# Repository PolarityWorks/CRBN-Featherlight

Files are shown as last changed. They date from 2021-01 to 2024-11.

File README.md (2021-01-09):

# CRBN-Featherlight

<br />The CRBN Featherlight is licensed under a <a rel="license" href="http://creativecommons.org/licenses/by-nc-sa/4.0/">Creative Commons Attribution-NonCommercial-ShareAlike 4.0 International License</a>.

The PCB and case design may be freely reproduced, modified, and manufactured for personal use and may not be reproduced for public sale.

If you have built upon this work please contact us at polarity.works.1@gmail.com. We fully support those looking to make new things and will most likely support your project.

[Build Guide](https://drive.google.com/file/d/1sr51WLZUvYGmcUbsTRLLeZIsZQXj4blm/view)

[Kits are sold here](https://keygem.store/collections/keyboards/products/group-buy-featherlight-40-kit)

[QMK Firmware](https://config.qmk.fm/#/crbn/LAYOUT_crbn_1x2u)

[ZMK Firmware](https://github.com/zmkfirmware/zmk/tree/main)

This little 40% ortho punches well above its weight and its price tag. Tough enough to survive life on the go or beating down someone that disses it.
It's got all the configuration options you'd ever want in a 40%. All the components are through-hole so it's a great first keyboard kit to put togethether.
You will need a pro micro for the PCB which gives you lots of options for extra features. You can solder in an elite c to get USB C or even a nice nano to make it wireless! There's plenty of room between the PCB and the bottom plate for a huge lithium battery.
This would be a vicious travel keyboard, a macro pad for productivity people, the first ortho for people who want to try ortho, or just a cute little keyboard to lend to people when they need one.

## Specifications
* Only 300g
* Stacked carbon fiber switch plate and bottom
* Supoport for a rotary encoder - this can be place in one of the corners
* Sevral bottom row layouts
* QMK and ZMK support

Main

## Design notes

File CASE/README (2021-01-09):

Dimensions:
Switch Plate thickness - 1.5mm
Bottom Plate thickness - 2mm
Inside corner radius - 1mm

Hardware needed:
M2x4mm machine screws   x24
M2x3mm M-F standoffs    x12
M2x6mm F-F standoffs    x12
M2x0.5mm washers        x12

M2x6mm machine screws   x2   (If using the optional feet)

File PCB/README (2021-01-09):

Components Needed:
1N4148 DO-35 Diodes               x48
6x6mm tactile button              x1
12x1 pin header 2.54mm pitch      x2
Pro Micro Compatible or Nice Nano x1
Key Switches                      x44-48

Optional:
EC11 Rotary Encoder               x1
Stabilisers (2u or 4u)            x1-2

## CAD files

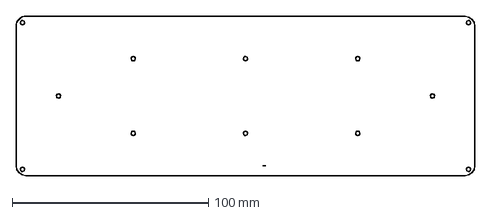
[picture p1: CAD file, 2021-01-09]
CASE/Bottom Plate.dxf
233.6 x 81.2 mm

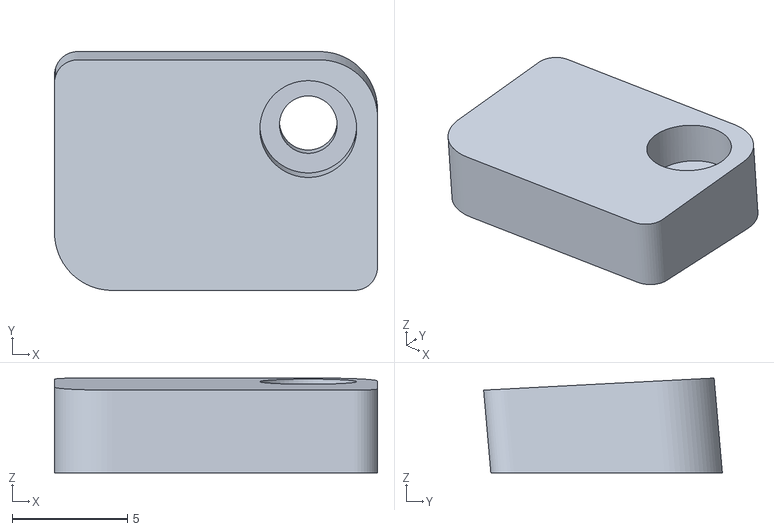
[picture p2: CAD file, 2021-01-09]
CASE/FEET/Foot - 3 degrees.stl
14.0 x 10.4 x 4.11

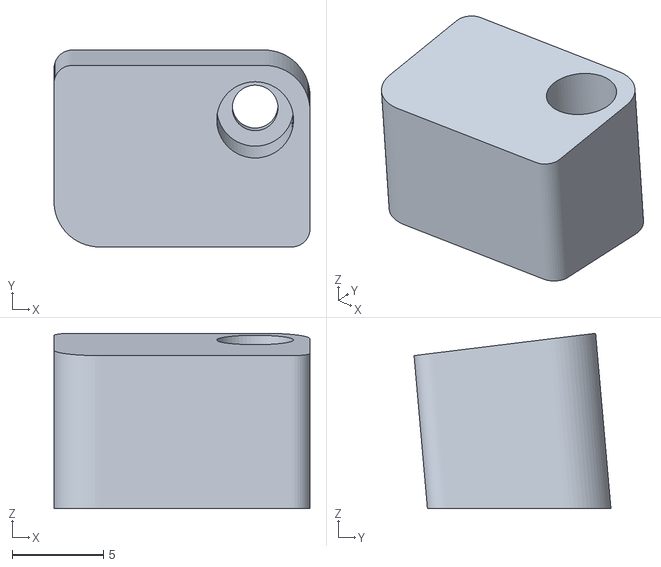
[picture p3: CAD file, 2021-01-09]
CASE/FEET/Foot - 7 degrees.stl
14.0 x 10.8 x 9.59

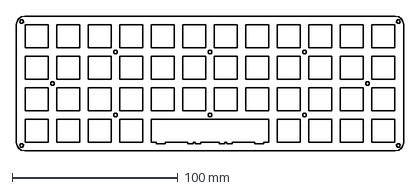
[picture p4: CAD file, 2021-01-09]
CASE/Switch Plate.dxf
233.6 x 81.2 mm

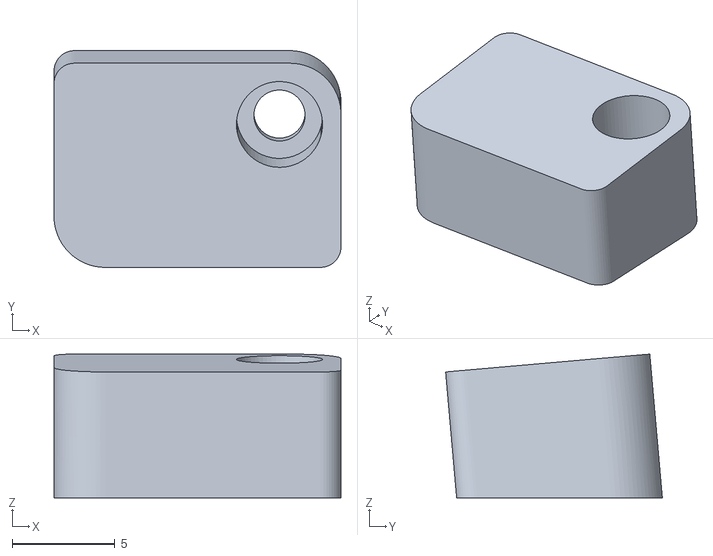
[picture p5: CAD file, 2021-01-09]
CASE/FEET/Foot - 5 degrees.stl
14.0 x 10.6 x 7.02

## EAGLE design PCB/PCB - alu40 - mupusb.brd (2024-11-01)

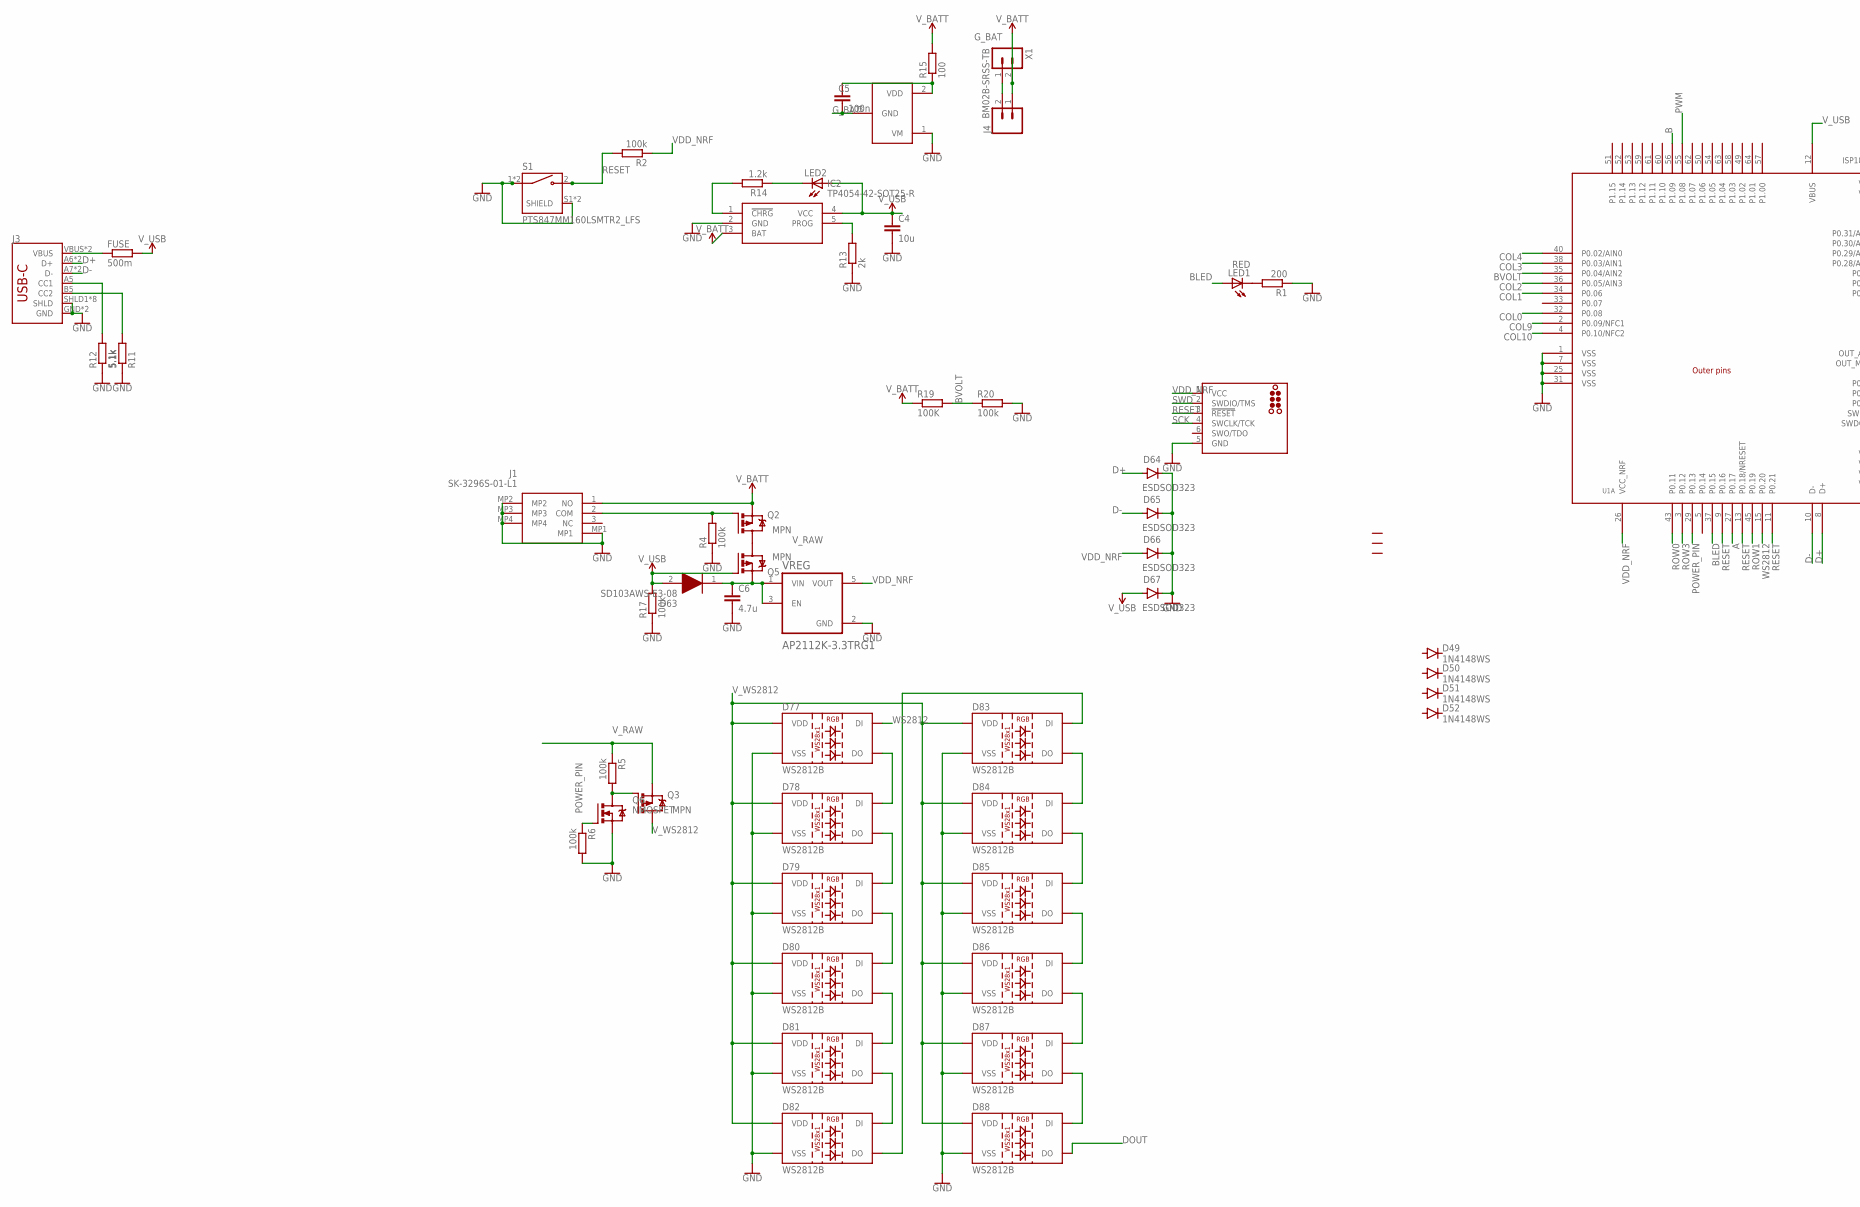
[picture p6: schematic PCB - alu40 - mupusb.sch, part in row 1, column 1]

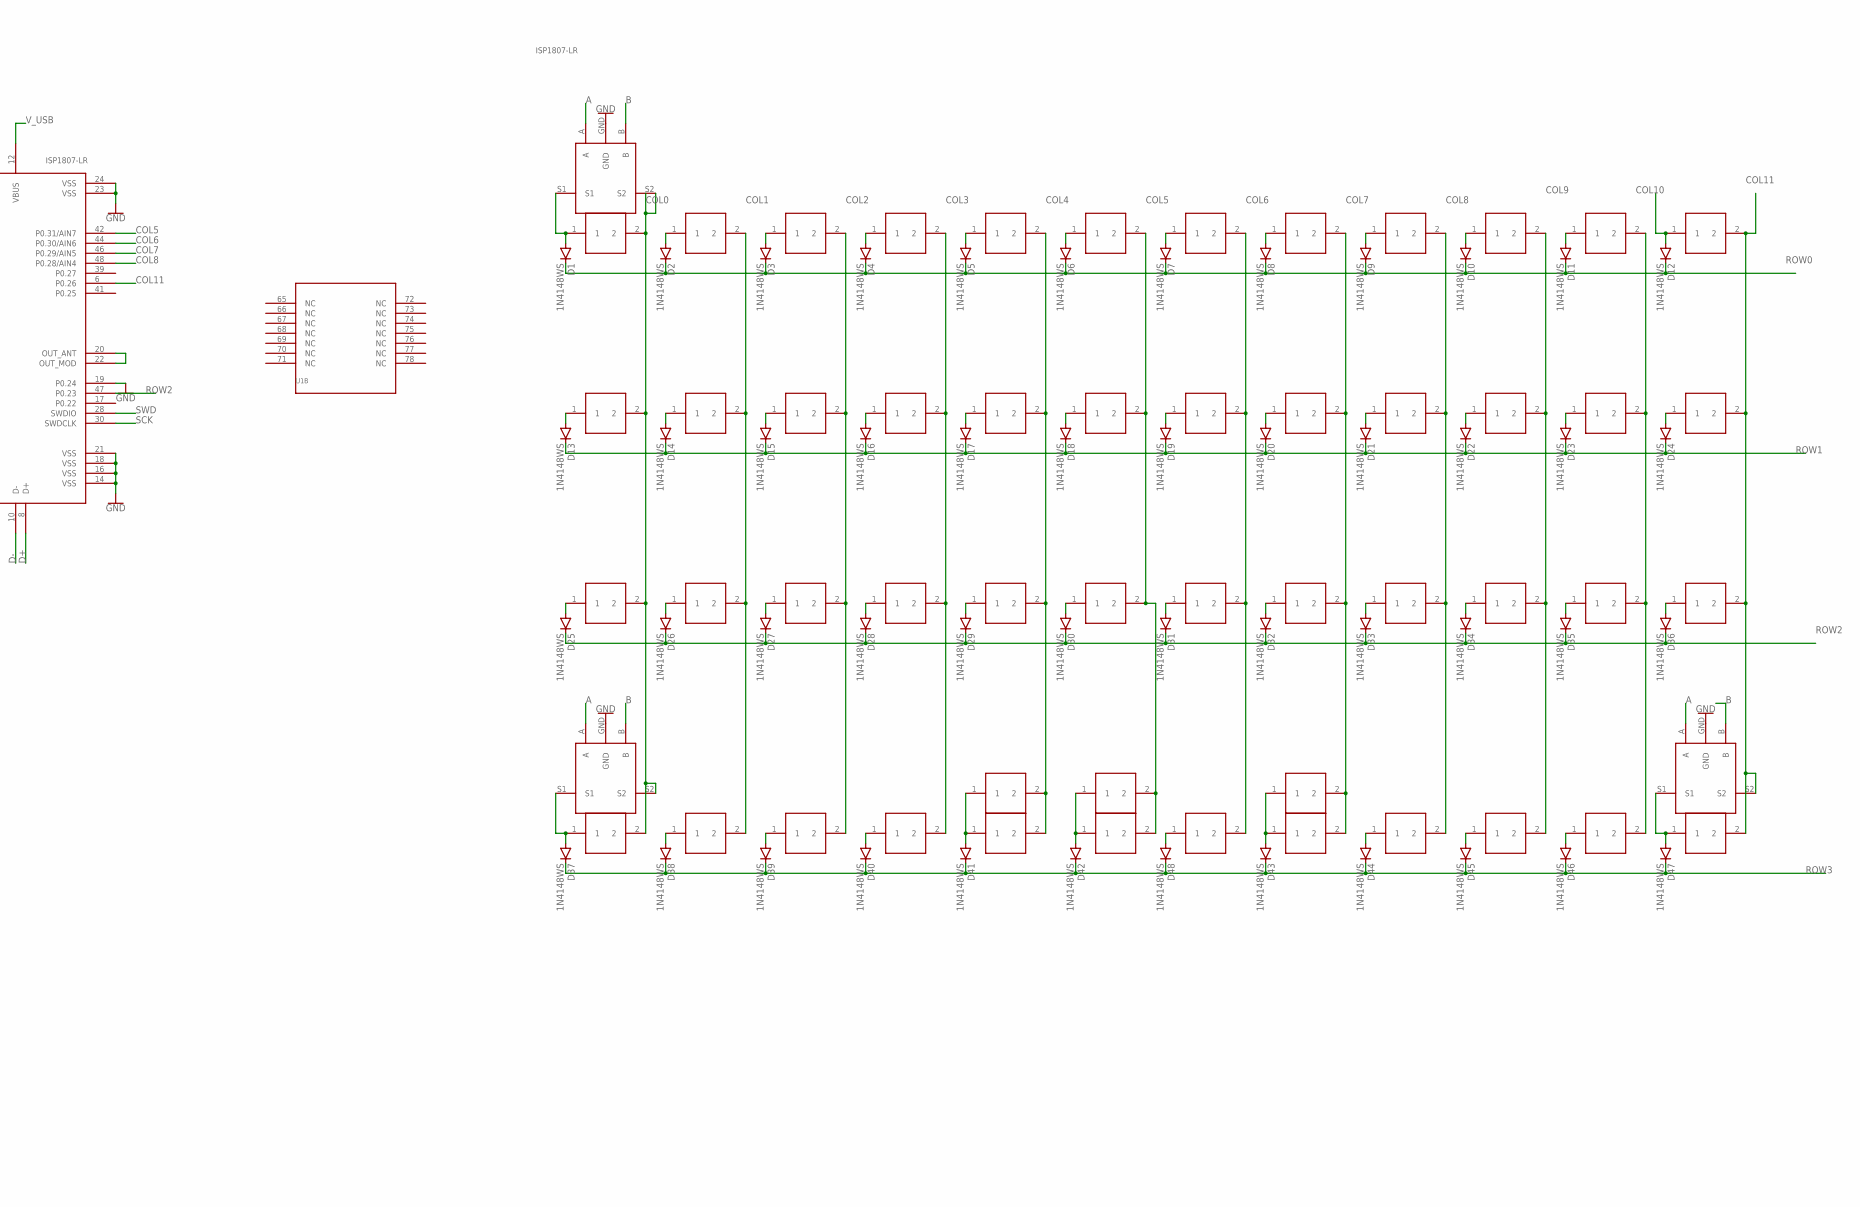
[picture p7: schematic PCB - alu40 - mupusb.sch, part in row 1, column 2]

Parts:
11, 12, 13, 14, 15, 16, 17, 18, 19, 21, 22, 23, 24, 25, 26, 27, 28, 29, 31, 32, 33, 34, 35, 36, 37, 38, 39, 41, 42, 43, 44, 45, 45-2, 46, 46-2, 47, 48, 48-2, 49, 110, 111, 112, 210, 211, 212, 310, 311, 312, 410, 411, 412: CHERRY
11ENC, 41ENC\, 412ENC: ENCODERHOLE; ENCODER
C4: 10u; C0603
C5: 100n; C0603
C6: 4.7u; C0603
D1, D2, D3, D4, D5, D6, D7, D8, D9, D10, D11, D12, D13, D14, D15, D16, D17, D18, D19, D20, D21, D22, D23, D24, D25, D26, D27, D28, D29, D30, D31, D32, D33, D34, D35, D36, D37, D38, D39, D40, D41, D42, D43, D44, D45, D46, D47, D48, D49, D50, D51, D52: 1N4148WS; SOD-323
D63: SD103AWS-E3-08; SOD2713X115N
D64, D65, D66, D67: ESDSOD323; SOD-323
D77, D78, D79, D80, D81, D82, D83, D84, D85, D86, D87, D88: WS2812B
FUSE: 500m; R0603
IC1: XB3303ASOT23; SOT23-3
IC2: TP4054-42-SOT25-R; SOT95P280X100-5N
J1: SK-3296S-01-L1; SK3296S01L1
J2: TC2030_SWD-MCP-NL; TC2030-MCP-NL
J3: SPARKFUN-CONNECTORS_USB_C; MUP-MIDMNT-SS
J4: CONN_02; 1X02
LED1: RED; CHIPLED_0805
LED2: LEDCHIPLED_0805; CHIPLED_0805
Q2, Q3, Q5: PMOSFET; SOT23; MPN SL2301S
Q6: NMOSFET; SOT23
R1: 200; R0603
R2, R4, R5, R6, R17, R20: 100k; R0603
R11, R12: 5.1k; R0603
R13: 2k; R0603
R14: 1.2k; R0603
R15: 100; R0603
R19: 100K; R0603
S1: PTS847MM160LSMTR2_LFS; SW_PTS847MM160LSMTR2_LFS
U1: ISP1807-LRISP1807-LR_ISP1807-LR; ISP1807-LR
U$8, U$9, U$10: STAB-2U
VREG: AP2112K-3.3TRG1; SOT95P285X140-5N
X1: BM02B-SRSS-TB

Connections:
A: 11ENC.A, 41ENC\.A, 412ENC.A, U1.27 (P0.17)
B: 11ENC.B, 41ENC\.B, 412ENC.B, U1.56 (P1.09)
BLED: LED1.A, U1.37 (P0.15)
BVOLT: R19.2, R20.1, U1.35 (P0.04/AIN2)
COL0: 11.2, 11ENC.S2, 21.2, 31.2, 41.2, 41ENC\.S2, U1.32 (P0.08)
COL1: 12.2, 22.2, 32.2, 42.2, U1.34 (P0.06)
COL2: 13.2, 23.2, 33.2, 43.2, U1.36 (P0.05/AIN3)
COL3: 14.2, 24.2, 34.2, 44.2, U1.38 (P0.03/AIN1)
COL4: 15.2, 25.2, 35.2, 45.2, 45-2.2, U1.40 (P0.02/AIN0)
COL5: 16.2, 26.2, 36.2, 46.2, 46-2.2, U1.42 (P0.31/AIN7)
COL6: 17.2, 27.2, 37.2, 47.2, U1.44 (P0.30/AIN6)
COL7: 18.2, 28.2, 38.2, 48.2, 48-2.2, U1.46 (P0.29/AIN5)
COL8: 19.2, 29.2, 39.2, 49.2, U1.48 (P0.28/AIN4)
COL9: 110.2, 210.2, 310.2, 410.2, U1.2 (P0.09/NFC1)
COL10: 111.2, 211.2, 311.2, 411.2, U1.4 (P0.10/NFC2)
COL11: 112.2, 212.2, 312.2, 412.2, 412ENC.S2, U1.6 (P0.26)
D+: D64.A, J3.A6 (D+), J3.B6 (D+), U1.8 (D+)
D-: D65.A, J3.A7 (D-), J3.B7 (D-), U1.10 (D-)
DOUT: D88.2 (DO)
GND: 11ENC.GND, 41ENC\.GND, 412ENC.GND, C4.2, C6.2, D64.C, D65.C, D66.C, D67.C, D77.3 (VSS), D78.3 (VSS), D79.3 (VSS), D80.3 (VSS), D81.3 (VSS), D82.3 (VSS), D83.3 (VSS), D84.3 (VSS), D85.3 (VSS), D86.3 (VSS), D87.3 (VSS), D88.3 (VSS), IC1.1 (VM), IC2.2 (GND), J1.MP1, J1.MP2, J1.MP3, J1.MP4, J2.5 (GND), J3.GND, J3.GND2 (GND), J3.SHLD1 (SHLD), J3.SHLD2 (SHLD), J3.SHLD3 (SHLD), J3.SHLD4 (SHLD), J3.SHLD5 (SHLD), J3.SHLD6 (SHLD), J3.SHLD7 (SHLD), J3.SHLD8 (SHLD), Q6.2 (S), R1.1, R4.1, R6.2, R11.1, R12.1, R13.1, R17.1, R20.2, S1.1 (COM), S1.3 (COM), S1.S1 (SHIELD), S1.S2 (SHIELD), U1.1 (VSS), U1.7 (VSS), U1.14 (VSS), U1.16 (VSS), U1.18 (VSS), U1.19 (P0.24), U1.21 (VSS), U1.23 (VSS), U1.24 (VSS), U1.25 (VSS), U1.31 (VSS), VREG.2 (GND)
G_BAT: C5.2, IC1.3 (GND), J4.2, X1.1
unnamed: 47.1, D48.A
unnamed: 12.1, D2.A
unnamed: 13.1, D3.A
unnamed: 14.1, D4.A
unnamed: 15.1, D5.A
unnamed: 16.1, D6.A
unnamed: 17.1, D7.A
unnamed: 18.1, D8.A
unnamed: 19.1, D9.A
unnamed: 110.1, D10.A
unnamed: 111.1, D11.A
unnamed: 112.1, D12.A
unnamed: 21.1, D13.A
unnamed: 22.1, D14.A
unnamed: 23.1, D15.A
unnamed: 24.1, D16.A
unnamed: 25.1, D17.A
unnamed: 26.1, D18.A
unnamed: 27.1, D19.A
unnamed: 28.1, D20.A
unnamed: 29.1, D21.A
unnamed: 210.1, D22.A
unnamed: 211.1, D23.A
unnamed: 212.1, D24.A
unnamed: 31.1, D25.A
unnamed: 32.1, D26.A
unnamed: 33.1, D27.A
unnamed: 34.1, D28.A
unnamed: 35.1, D29.A
unnamed: 36.1, D30.A
unnamed: 37.1, D31.A
unnamed: 38.1, D32.A
unnamed: 39.1, D33.A
unnamed: 310.1, D34.A
unnamed: 311.1, D35.A
unnamed: 312.1, D36.A
unnamed: D77.2 (DO), D78.4 (DI)
unnamed: 42.1, D38.A
unnamed: 43.1, D39.A
unnamed: 44.1, D40.A
unnamed: 45.1, 45-2.1, D41.A
unnamed: U1.20 (OUT_ANT), U1.22 (OUT_MOD)
unnamed: 48.1, 48-2.1, D43.A
unnamed: 49.1, D44.A
unnamed: 410.1, D45.A
unnamed: 411.1, D46.A
unnamed: 46.1, 46-2.1, D42.A
unnamed: 412.1, 412ENC.S1, D47.A
unnamed: 41.1, 41ENC\.S1, D37.A
unnamed: LED1.C, R1.2
unnamed: C5.1, IC1.2 (VDD), R15.1
unnamed: IC2.5 (PROG), R13.2
unnamed: J3.A5 (CC1), R12.2
unnamed: J3.B5 (CC2), R11.2
unnamed: IC2.1 (!CHRG), R14.2
unnamed: LED2.C, R14.1
unnamed: Q2.3 (D), Q5.3 (D)
unnamed: FUSE.1, J3.VBUS, J3.VBUS2 (VBUS)
unnamed: 11.1, 11ENC.S1, D1.A
unnamed: J1.2 (COM), Q2.1 (G), R4.2
unnamed: Q3.1 (G), Q6.3 (D), R5.2
unnamed: D78.2 (DO), D79.4 (DI)
unnamed: D79.2 (DO), D80.4 (DI)
unnamed: D80.2 (DO), D81.4 (DI)
unnamed: D81.2 (DO), D82.4 (DI)
unnamed: D82.2 (DO), D83.4 (DI)
unnamed: D83.2 (DO), D84.4 (DI)
unnamed: D84.2 (DO), D85.4 (DI)
unnamed: D85.2 (DO), D86.4 (DI)
unnamed: D86.2 (DO), D87.4 (DI)
unnamed: D87.2 (DO), D88.4 (DI)
POWER_PIN: Q6.1 (G), R6.1, U1.29 (P0.13)
PWM: U1.55 (P1.08)
RESET: J2.3 (!RESET), R2.2, S1.2 (NO), U1.9 (P0.16), U1.11 (P0.21), U1.13 (P0.18/NRESET)
ROW0: D1.C, D2.C, D3.C, D4.C, D5.C, D6.C, D7.C, D8.C, D9.C, D10.C, D11.C, D12.C, U1.43 (P0.11)
ROW1: D13.C, D14.C, D15.C, D16.C, D17.C, D18.C, D19.C, D20.C, D21.C, D22.C, D23.C, D24.C, U1.45 (P0.19)
ROW2: D25.C, D26.C, D27.C, D28.C, D29.C, D30.C, D31.C, D32.C, D33.C, D34.C, D35.C, D36.C, U1.47 (P0.23)
ROW3: D37.C, D38.C, D39.C, D40.C, D41.C, D42.C, D43.C, D44.C, D45.C, D46.C, D47.C, D48.C, U1.3 (P0.12)
SCK: J2.4 (SWCLK/TCK), U1.30 (SWDCLK)
SWD: J2.2 (SWDIO/TMS), U1.28 (SWDIO)
VDD_NRF: D66.A, J2.1 (VCC), R2.1, U1.26 (VCC_NRF), VREG.5 (VOUT)
V_BATT: IC2.3 (BAT), J1.1 (NO), J4.1, Q2.2 (S), R15.2, R19.1, X1.2
V_RAW: C6.1, D63.1 (K), Q3.2 (S), Q5.2 (S), R5.1, VREG.1 (VIN), VREG.3 (EN)
V_USB: C4.1, D63.2 (A), D67.A, FUSE.2, IC2.4 (VCC), LED2.A, Q5.1 (G), R17.2, U1.12 (VBUS)
V_WS2812: D77.1 (VDD), D78.1 (VDD), D79.1 (VDD), D80.1 (VDD), D81.1 (VDD), D82.1 (VDD), D83.1 (VDD), D84.1 (VDD), D85.1 (VDD), D86.1 (VDD), D87.1 (VDD), D88.1 (VDD), Q3.3 (D)
WS2812: D77.4 (DI), U1.15 (P0.20)

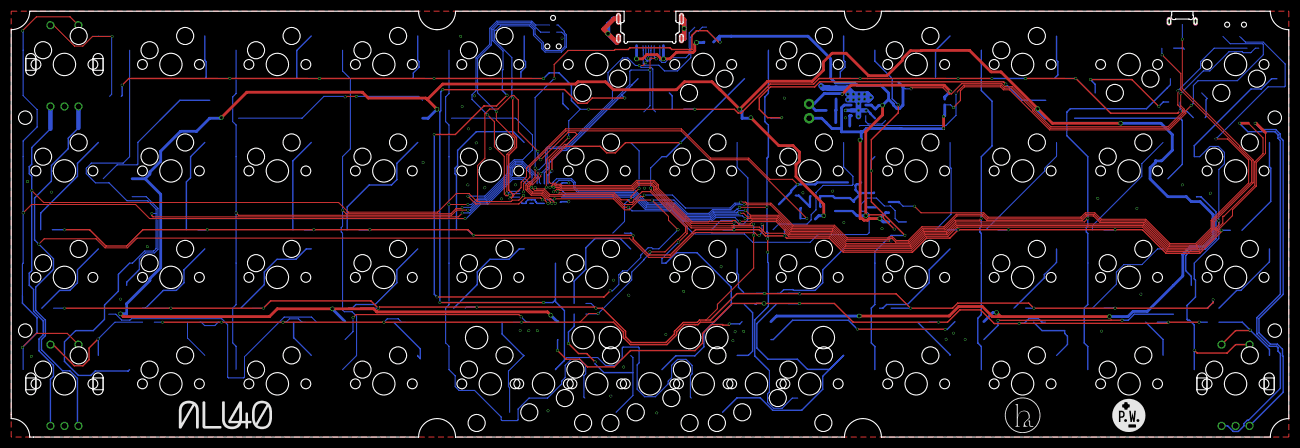
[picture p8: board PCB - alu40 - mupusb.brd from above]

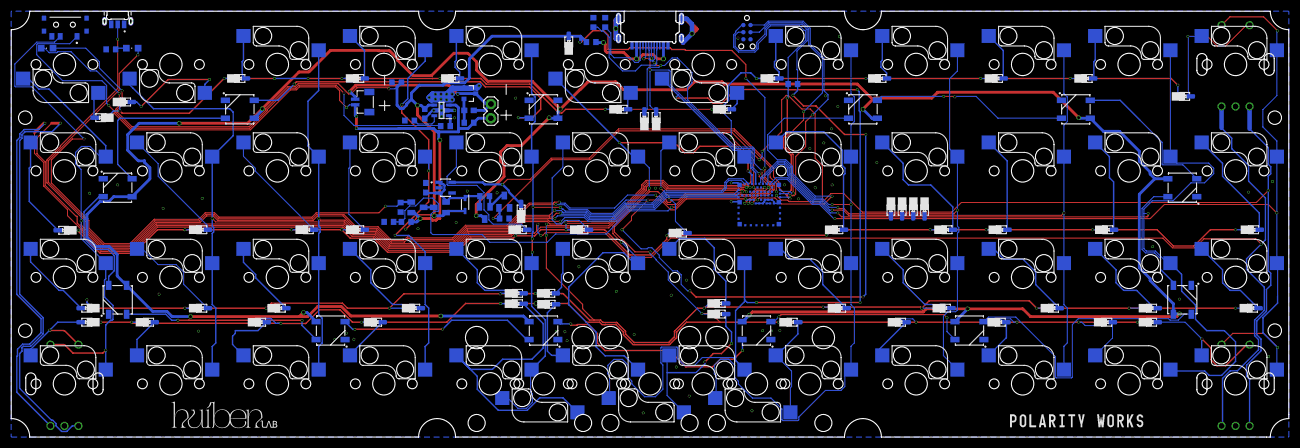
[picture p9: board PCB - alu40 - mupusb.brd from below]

Board: 2 copper layers, 228.0 x 76.0 mm, 159 parts (102 on the bottom side), 105 nets.

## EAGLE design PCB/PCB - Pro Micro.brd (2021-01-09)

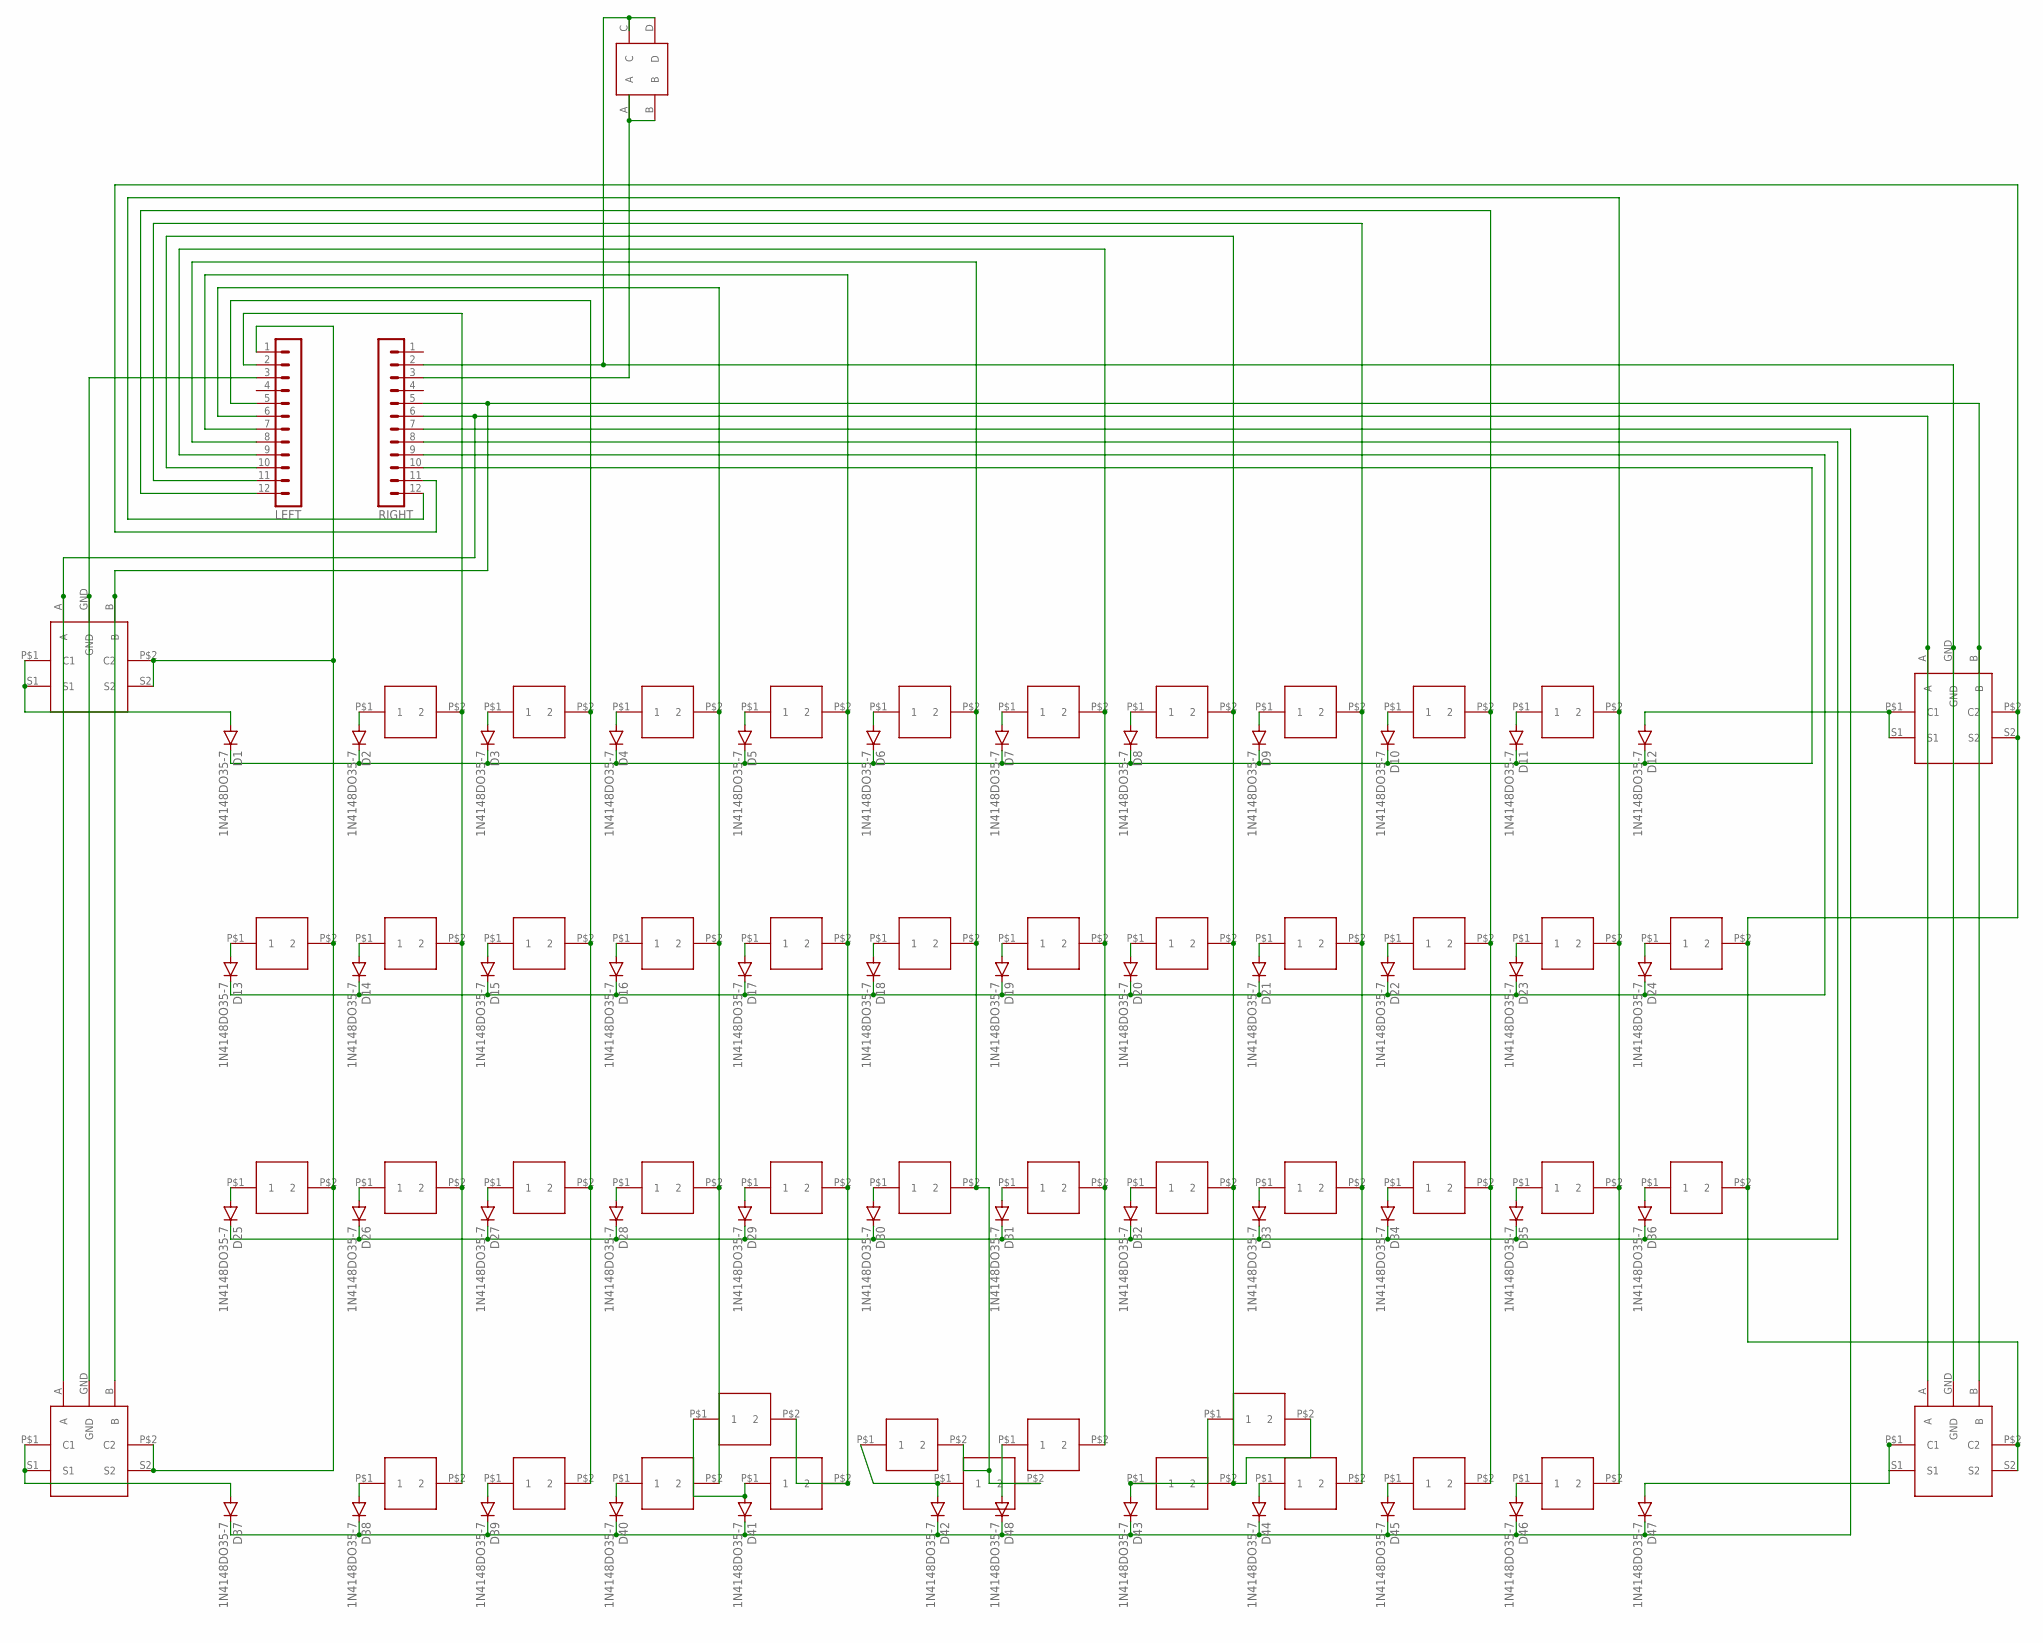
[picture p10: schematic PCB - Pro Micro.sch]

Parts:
1, 2, 3, 4, 12, 13, 14, 15, 16, 17, 18, 19, 21, 22, 23, 24, 25, 26, 27, 28, 29, 31, 32, 33, 34, 35, 36, 37, 38, 39, 42, 43, 44, 45, 46, 47, 48, 49, 110, 111, 210, 211, 212, 310, 311, 312, 410: CHERRY-SOLDER
D1, D2, D3, D4, D5, D6, D7, D8, D9, D10, D11, D12, D13, D14, D15, D16, D17, D18, D19, D20, D21, D22, D23, D24, D25, D26, D27, D28, D29, D30, D31, D32, D33, D34, D35, D36, D37, D38, D39, D40, D41, D42, D43, D44, D45, D46, D47, D48: 1N4148DO35-7; DO35-7
LEFT: MA12-1
RIGHT: MA12-1
U$1: BUTTON
U$2, U$3, U$4, U$5: CHERRY-ENCODER

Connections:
unnamed: 3.P$2 (2), 15.P$2 (2), 25.P$2 (2), 35.P$2 (2), 45.P$2 (2), LEFT.7
unnamed: 12.P$1 (1), D2.A
unnamed: 13.P$1 (1), D3.A
unnamed: 14.P$1 (1), D4.A
unnamed: 15.P$1 (1), D5.A
unnamed: 16.P$1 (1), D6.A
unnamed: 17.P$1 (1), D7.A
unnamed: 18.P$1 (1), D8.A
unnamed: 19.P$1 (1), D9.A
unnamed: 110.P$1 (1), D10.A
unnamed: 111.P$1 (1), D11.A
unnamed: D12.A, U$2.P$1 (C1), U$2.S1
unnamed: 21.P$1 (1), D13.A
unnamed: 22.P$1 (1), D14.A
unnamed: 23.P$1 (1), D15.A
unnamed: 24.P$1 (1), D16.A
unnamed: 25.P$1 (1), D17.A
unnamed: 26.P$1 (1), D18.A
unnamed: 27.P$1 (1), D19.A
unnamed: 28.P$1 (1), D20.A
unnamed: 29.P$1 (1), D21.A
unnamed: 210.P$1 (1), D22.A
unnamed: 211.P$1 (1), D23.A
unnamed: 212.P$1 (1), D24.A
unnamed: 31.P$1 (1), D25.A
unnamed: 32.P$1 (1), D26.A
unnamed: 33.P$1 (1), D27.A
unnamed: 34.P$1 (1), D28.A
unnamed: 35.P$1 (1), D29.A
unnamed: 36.P$1 (1), D30.A
unnamed: 37.P$1 (1), D31.A
unnamed: 38.P$1 (1), D32.A
unnamed: 39.P$1 (1), D33.A
unnamed: 310.P$1 (1), D34.A
unnamed: 311.P$1 (1), D35.A
unnamed: 312.P$1 (1), D36.A
unnamed: 21.P$2 (2), 31.P$2 (2), LEFT.1, U$3.P$2 (C2), U$3.S2, U$4.P$2 (C2), U$4.S2
unnamed: 42.P$1 (1), D38.A
unnamed: 43.P$1 (1), D39.A
unnamed: 44.P$1 (1), D40.A
unnamed: 3.P$1 (1), 45.P$1 (1), D41.A
unnamed: 1.P$1 (1), 46.P$1 (1), D42.A
unnamed: 4.P$1 (1), 47.P$1 (1), D43.A
unnamed: 48.P$1 (1), D44.A
unnamed: 49.P$1 (1), D45.A
unnamed: 410.P$1 (1), D46.A
unnamed: D47.A, U$5.P$1 (C1), U$5.S1
unnamed: D37.A, U$4.P$1 (C1), U$4.S1
unnamed: 212.P$2 (2), 312.P$2 (2), RIGHT.11, U$2.P$2 (C2), U$2.S2, U$5.P$2 (C2), U$5.S2
unnamed: 12.P$2 (2), 22.P$2 (2), 32.P$2 (2), 42.P$2 (2), LEFT.2
unnamed: D37.C, D38.C, D39.C, D40.C, D41.C, D42.C, D43.C, D44.C, D45.C, D46.C, D47.C, D48.C, RIGHT.7
unnamed: D1.C, D2.C, D3.C, D4.C, D5.C, D6.C, D7.C, D8.C, D9.C, D10.C, D11.C, D12.C, RIGHT.10
unnamed: D13.C, D14.C, D15.C, D16.C, D17.C, D18.C, D19.C, D20.C, D21.C, D22.C, D23.C, D24.C, RIGHT.9
unnamed: D25.C, D26.C, D27.C, D28.C, D29.C, D30.C, D31.C, D32.C, D33.C, D34.C, D35.C, D36.C, RIGHT.8
unnamed: RIGHT.2, U$1.C, U$1.D, U$2.GND, U$5.GND
unnamed: LEFT.3, U$3.GND, U$4.GND
unnamed: 13.P$2 (2), 23.P$2 (2), 33.P$2 (2), 43.P$2 (2), LEFT.5
unnamed: 111.P$2 (2), 211.P$2 (2), 311.P$2 (2), 410.P$2 (2), RIGHT.12
unnamed: RIGHT.6, U$2.A, U$3.A, U$4.A, U$5.A
unnamed: D1.A, U$3.P$1 (C1), U$3.S1
unnamed: 14.P$2 (2), 24.P$2 (2), 34.P$2 (2), 44.P$2 (2), LEFT.6
unnamed: RIGHT.5, U$2.B, U$3.B, U$4.B, U$5.B
unnamed: 2.P$1 (1), D48.A
unnamed: 2.P$2 (2), 17.P$2 (2), 27.P$2 (2), 37.P$2 (2), LEFT.9
unnamed: 49.P$2 (2), 110.P$2 (2), 210.P$2 (2), 310.P$2 (2), LEFT.12
unnamed: 1.P$2 (2), 16.P$2 (2), 26.P$2 (2), 36.P$2 (2), 46.P$2 (2), LEFT.8
unnamed: RIGHT.3, U$1.A, U$1.B
unnamed: 4.P$2 (2), 18.P$2 (2), 28.P$2 (2), 38.P$2 (2), 47.P$2 (2), LEFT.10
unnamed: 19.P$2 (2), 29.P$2 (2), 39.P$2 (2), 48.P$2 (2), LEFT.11

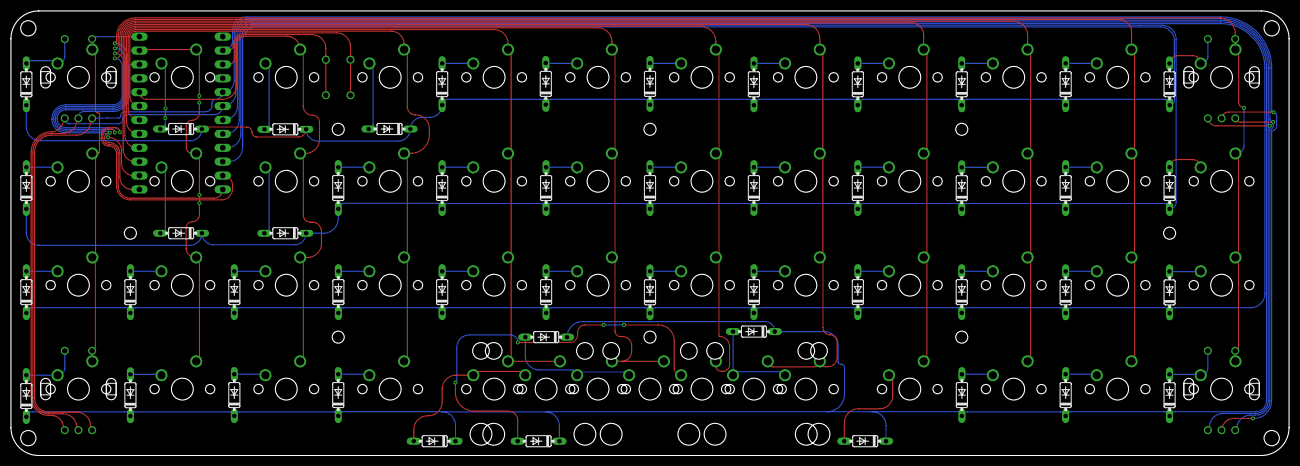
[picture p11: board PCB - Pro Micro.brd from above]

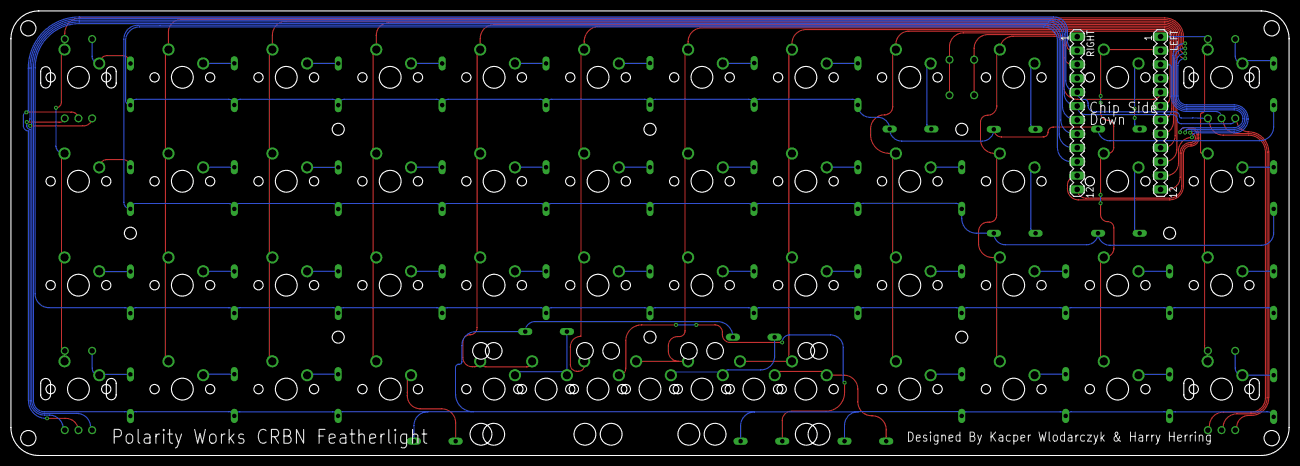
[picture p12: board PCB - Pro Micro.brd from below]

Board: 2 copper layers, 233.7 x 81.3 mm, 102 parts (2 on the bottom side), 69 nets.

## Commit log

2021-12-04 new pcb push
    [PCB - nrf52840.brd, PCB - nrf52840.sch]
2021-12-30 DRC fixes and GERBERs
2022-10-17 alu40 cimmut
    [PCB - alu40.brd, PCB - alu40.sch]
2022-10-17 Moved connector - added silk
    [PCB - alu40.brd]
2022-10-17 Updated connector position
    [PCB - alu40.brd]
2022-10-17 Final connector update
    [PCB - alu40.brd]
2022-10-21 Add standoffs
    [PCB - alu40.brd, PCB - alu40.sch]
2022-10-21 Update PCB - alu40.brd
    [PCB - alu40.brd]
2022-10-21 Add Bcream
    [PCB - alu40.brd, PCB - alu40.sch]
2022-12-11 Move reset switch
    [PCB - alu40.brd, PCB - alu40.sch]
2023-02-04 Remove unnecessary swd pin
    [PCB - alu40.brd, PCB - alu40.sch]
2023-03-04 Add Via
    [PCB - alu40.brd, PCB - alu40.sch]
2023-03-13 add silk, spare diodes, move D1
    [PCB - alu40.brd, PCB - alu40.sch]
2023-03-13 Add lgoos to unused layer
    [PCB - alu40.brd]
2023-03-16 logo position update
    [PCB - alu40.brd, PCB - alu40.sch]
2023-03-20 Change component vals
    [PCB - alu40.brd, PCB - alu40.sch]
2023-06-01 New usb prototyps
    [PCB - alu40 - mupusb.brd, PCB - alu40 - mupusb.sch]
2023-06-02 Generated GERBERs
2023-12-30 Add Tagconnect and thermal relif for tp4054
    [PCB - alu40 - mupusb.sch]
2024-06-02 most of new updates
    Needs new reset and power switch, new USB port
    [PCB - alu40 - mupusb.sch]
2024-06-03 Route new switch footprints
    [PCB - alu40 - mupusb.brd, PCB - alu40 - mupusb.sch]
2024-08-06 Commit gerbers
    [PCB - alu40 - mupusb.brd]
2024-08-06 tweak usb
    [PCB - alu40 - mupusb.brd, PCB - alu40 - mupusb.sch]
2024-08-29 Move silk to custom layers
    [PCB - alu40 - mupusb.brd]
2024-10-31 Move LEDs across bottom
    [PCB - alu40 - mupusb.brd]
2024-11-01 Move top and bottom layer graphics
    [PCB - alu40 - mupusb.brd]

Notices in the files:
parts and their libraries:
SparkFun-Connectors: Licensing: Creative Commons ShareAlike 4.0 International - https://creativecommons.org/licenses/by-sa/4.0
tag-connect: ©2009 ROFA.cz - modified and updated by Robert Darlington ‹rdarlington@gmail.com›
